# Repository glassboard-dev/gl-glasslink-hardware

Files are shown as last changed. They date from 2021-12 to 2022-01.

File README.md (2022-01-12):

<p align="center">
  <h3 align="center">⚡ Glasslink</h3>
  <p align="center">
    CMSIS-DAP Compatible Debugger & Programmer for ARM M-Cores
  </p>
</p>

<br />


### Development ⚡
The Glasslink hardware is currently developed in the open source ECAD software [KiCAD](https://www.kicad.org/). The board was created using as many of the included component symbols and footprints as possible. Any custom components are located in the ```Glasslink.lib``` and ```Glasslink.pretty``` files. Additional 3D models were also added to the designa and can be found in the ```models``` folder. The KiCAD [Teardrops](https://github.com/stimulu/kicad-teardrops) extension was used to add teardrops to SMD pads and Vias.

### Board Bring-up 🔼
Once you have a physical piece of hardware in hand, you can begin flashing and setting the device up for your use. The Glasslink hardware is intended to run the open-source firmware [DAPLink](https://github.com/ARMmbed/DAPLink/tree/develop) which supports Drag-N-Drop flashing of certain targets, CDC serial port, CMSIS-DAP WinUSB & HID debug channel as well as WebUSB debug channels. The tested Firwmare has been built using the current ```develop``` branch (as of ```12/10/2021```) using the ```GNU Arm Embedded Toolchain 10-2020-q4-major``` toolchain. More information on building standalone firmware or firmware intended for a specific target (utilizing MSC/Drag-N-Drop) - see [here](https://github.com/ARMmbed/DAPLink/tree/develop/docs).

Once you are ready to flash firmware to the DAPLink hardware, you can utilize the built-in NXP USB ROM Bootloader. A fresh piece of hardware should enumerate immediately into the bootloader when the USB is plugged in. Otherwise, you can hold down the ```nRESET``` pushbutton while plugging in the USB. The ROM Bootloader will enumerate as a MSD labeled ```CRP_DISABLED```.

#### Windows
On windows, to flash a piece of Glasslink hardware you can simply drag your compiled firmware onto the storage device found in File Explorer.

#### Linux
On linux, the ```dd``` command is used to write the firmware to your Glasslink hardware
```console
sudo dd if=lpc11u35_if.bin of=/media/user/CRP\ DISABLD/firmware.bin conv=notrunc
```

### Usage 💻
There are two common applications for utilizing the Glasslink debug probe: [PyOCD](https://pyocd.io/) and [OpenOCD](https://openocd.org/). Check the documentation for each on how to connect a probe, flash a target, debug, etc.

#### CDC Serial Port
The Glasslink hardware enumerates not only as a CMSIS-DAP probe, but also as a CDC serial port. This port can be utilized to send UART/serial data from your Target to a connected Host PC. On Windows a new ```COM``` port should enumerate and on Linux a new ```ACM``` port should enumerate when the Glasslink probe is connected.

To connect the Glasslink serial lines to your targets UART, please reference the 10pin ARM header pinout below. The current design assumes that you are creating your target hardware and have the ability to route your UART pins to the "unused" pins of the SWD header.

**```NOTE - The UART switching for TX<->RX and RX<->TX is done for you on the Glasslink hardware. The target TX pin sould go to pin 9 of the 10pin ARM header.```**

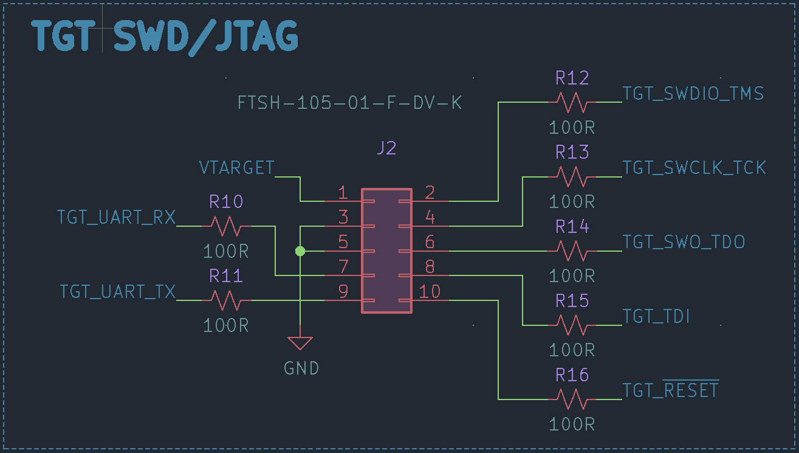
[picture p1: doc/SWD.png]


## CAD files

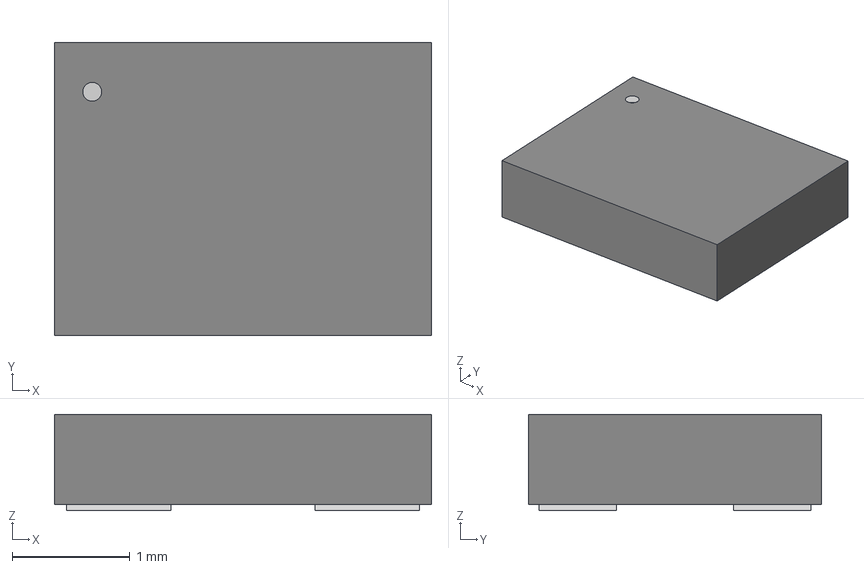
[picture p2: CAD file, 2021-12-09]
models/ECS-120-20-33-CKM-TR/2021-12-09_15-51-46/STEP/SMD_EXC-32_CRYSTAL_3P2X2P5_ECS.step
3.20 x 2.49 x 0.815 mm

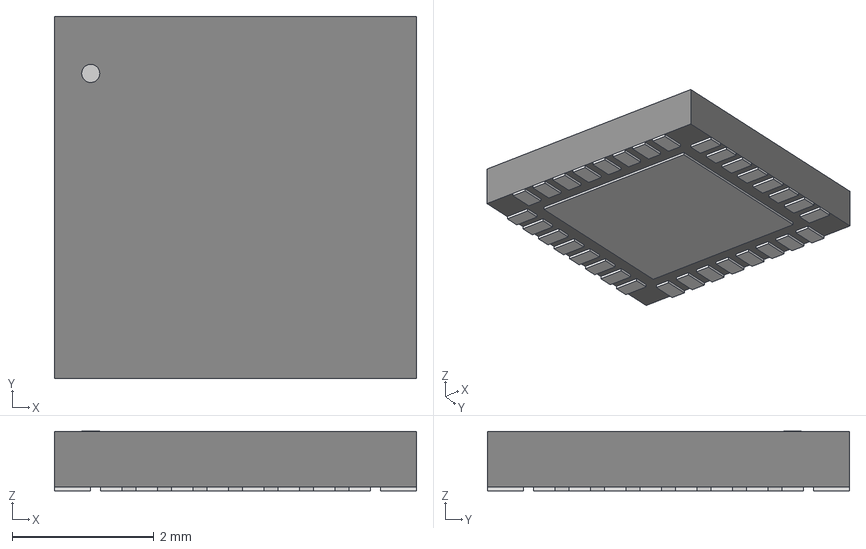
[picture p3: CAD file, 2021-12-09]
models/LPC11U35FHI33-501Y/2021-12-09_15-47-32/STEP/HVQFN32_SOT617-3_NXP.step
5.11 x 5.11 x 0.841 mm

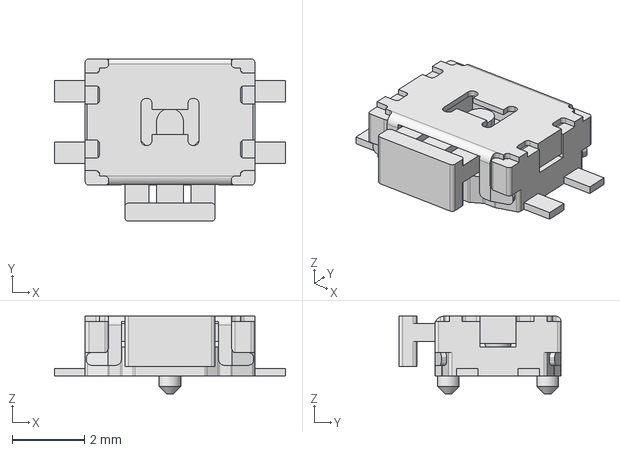
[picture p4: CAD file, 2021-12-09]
models/TL1014BF160QG/TL1014BFxxxQG.stp
6.40 x 4.50 x 2.15 mm

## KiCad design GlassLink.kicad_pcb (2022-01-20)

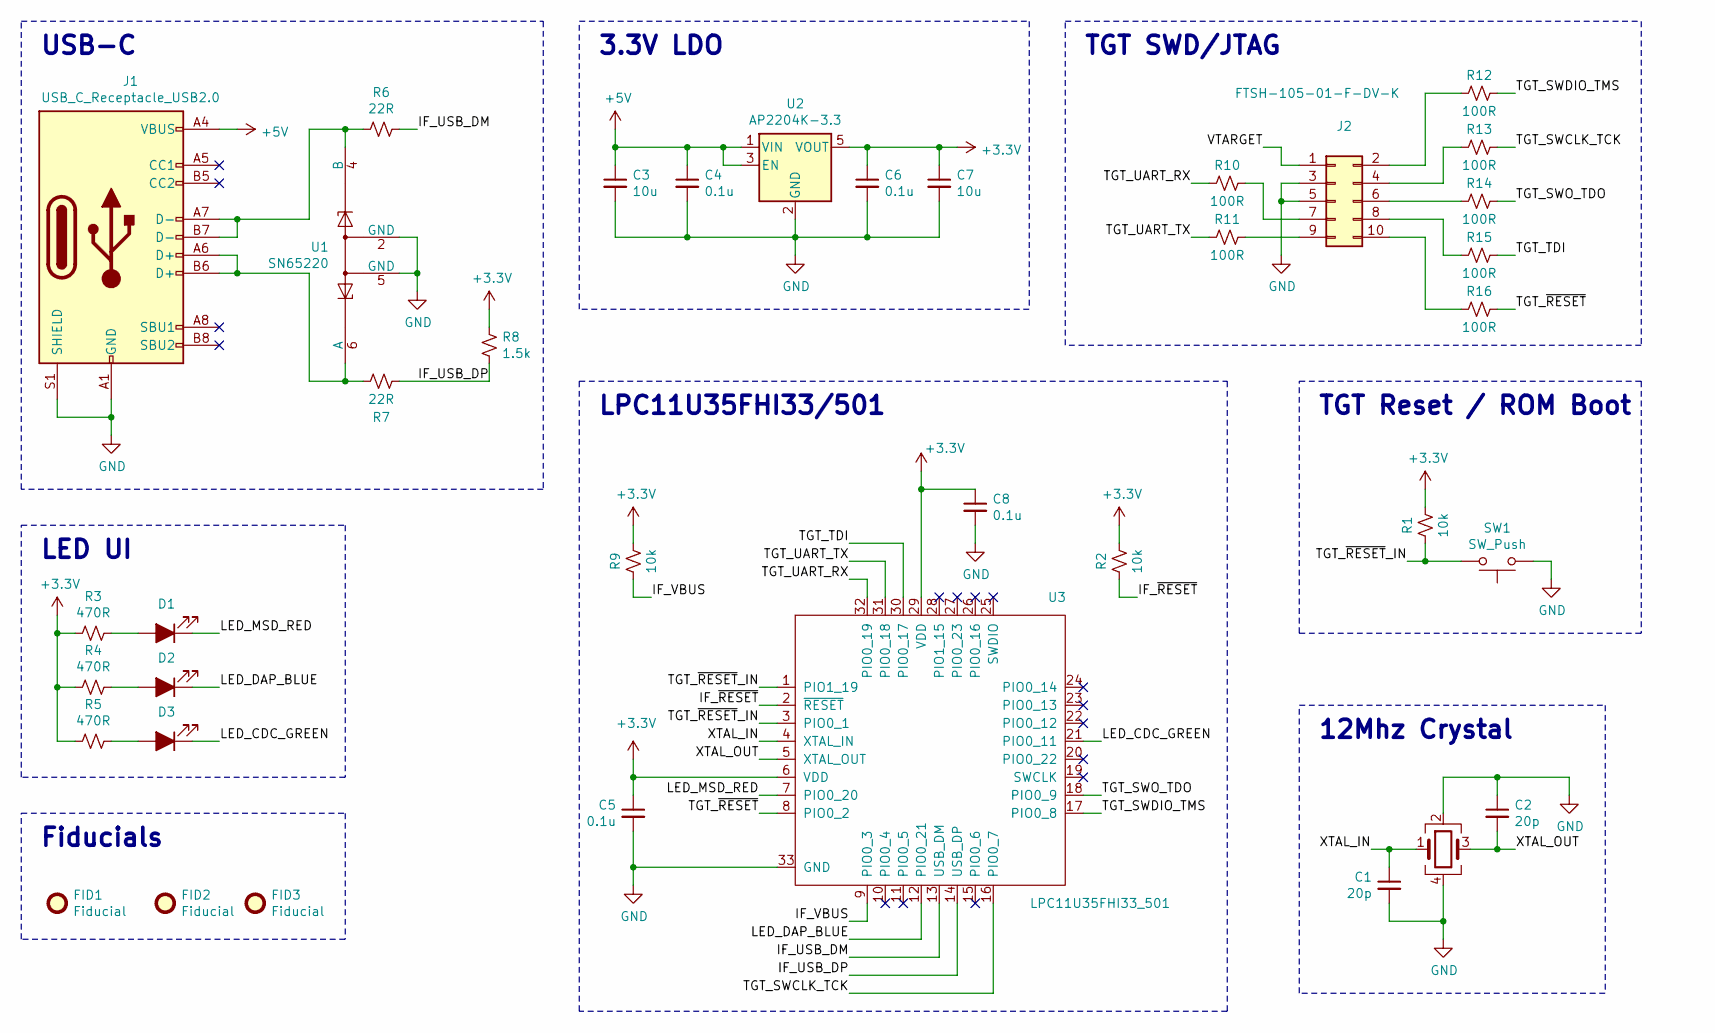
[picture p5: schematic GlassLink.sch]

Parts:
C1, C2: 20p; C_0402_1005Metric
C3, C7: 10u; C_0402_1005Metric
C4, C5, C6, C8: 0.1u; C_0402_1005Metric
D1: RED; LED_0603_1608Metric
D2: BLUE; LED_0603_1608Metric
D3: GREEN; LED_0603_1608Metric
FID1, FID2, FID3: Fiducial; Fiducial_0.5mm_Mask1mm
J1: USB_C_Receptacle_USB2.0; USB_C_Receptacle_GCT_USB4085
J2: FTSH-105-01-F-DV-K; PinHeader_2x05_P1.27mm_Vertical_SMD
R1, R2, R9: 10k; R_0402_1005Metric
R3, R4, R5: 470R; R_0402_1005Metric
R6, R7: 22R; R_0402_1005Metric
R8: 1.5k; R_0402_1005Metric
R10, R11, R12, R13, R14, R15, R16: 100R; R_0402_1005Metric
SW1: SW_Push; Panasonic_EVQPUL_EVQPUC
U1: SN65220; SOT-23-6
U2: AP2204K-3.3; SOT-23-5
U3: LPC11U35FHI33_501; QFN-32_EP_6.2x6.2_Pitch0.5mm
Y1: ECS-120-20-30B-TR; Crystal_SMD_5032-4Pin_5.0x3.2mm

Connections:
+3V3: C5.1, C6.1, C7.1, C8.1, R1.1, R2.1, R3.2, R4.2, R5.2, R8.1, R9.1, U2.5 (VOUT), U3.6 (VDD), U3.29 (VDD)
+5V: C3.1, C4.1, J1.A4 (VBUS), J1.A9 (VBUS), J1.B4 (VBUS), J1.B9 (VBUS), U2.1 (VIN), U2.3 (EN)
/IF_USB_DM: R6.1, U3.13 (USB_DM)
/IF_USB_DP: R7.2, R8.2, U3.14 (USB_DP)
/IF_VBUS: R9.2, U3.9 (PIO0_3)
/IF_~RESET: R2.2, U3.2 (~RESET)
/LED_CDC_GREEN: D3.1 (K), U3.21 (PIO0_11)
/LED_DAP_BLUE: D2.1 (K), U3.12 (PIO0_21)
/LED_MSD_RED: D1.1 (K), U3.7 (PIO0_20)
/TGT_SWCLK_TCK: R13.1, U3.16 (PIO0_7)
/TGT_SWDIO_TMS: R12.1, U3.17 (PIO0_8)
/TGT_SWO_TDO: R14.1, U3.18 (PIO0_9)
/TGT_TDI: R15.1, U3.30 (PIO0_17)
/TGT_UART_RX: R10.2, U3.32 (PIO0_19)
/TGT_UART_TX: R11.2, U3.31 (PIO0_18)
/TGT_~RESET: R16.1, U3.8 (PIO0_2)
/TGT_~RESET~_IN: R1.2, SW1.2, U3.1 (PIO1_19), U3.3 (PIO0_1)
/VTARGET: J2.1
/XTAL_IN: C1.1, U3.4 (XTAL_IN), Y1.1
/XTAL_OUT: C2.2, U3.5 (XTAL_OUT), Y1.3
GND: C1.2, C2.1, C3.2, C4.2, C5.2, C6.2, C7.2, C8.2, J1.A1 (GND), J1.A12 (GND), J1.B1 (GND), J1.B12 (GND), J1.S1 (SHIELD), J2.3, J2.5, SW1.1, U1.2 (GND), U1.5 (GND), U2.2 (GND), U3.33 (GND), Y1.2, Y1.4
unnamed: D1.2 (A), R3.1
unnamed: D2.2 (A), R4.1
unnamed: D3.2 (A), R5.1
unnamed: J1.A6 (D+), J1.B6 (D+), R7.1, U1.6 (A)
unnamed: J1.A7 (D-), J1.B7 (D-), R6.2, U1.4 (B)
unnamed: J2.2, R12.2
unnamed: J2.4, R13.2
unnamed: J2.6, R14.2
unnamed: J2.7, R10.1
unnamed: J2.8, R15.2
unnamed: J2.9, R11.1
unnamed: J2.10, R16.2

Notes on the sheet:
USB-C
3.3V LDO
TGT SWD/JTAG
LED UI
LPC11U35FHI33/501
12Mhz Crystal
TGT Reset / ROM Boot
Fiducials

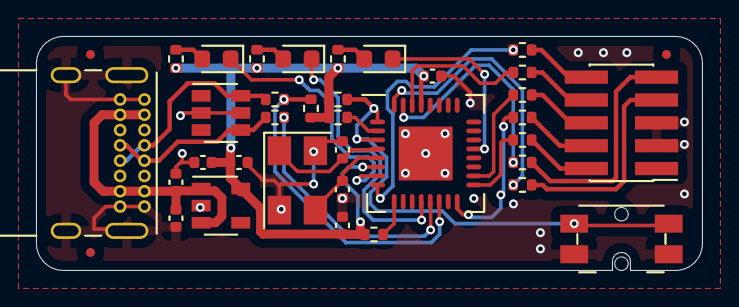
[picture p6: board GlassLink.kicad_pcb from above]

Board: 2 copper layers, 37.0 x 13.0 mm, 37 parts (0 on the bottom side), 32 nets.

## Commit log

2020-12-08 First commit of project files.
    [GlassLink-PCB.PcbDoc, GlassLink-PRJ.PrjPCB, [01] Title Page.SchDoc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]
2020-12-10 WIP: Components placed
    Awaiting track layout.
    [GlassLink-PCB.PcbDoc, GlassLink-PRJ.PrjPCB, [03] SCH-03.SchDoc]
2020-12-10 WIP: Layout finished
    In review
    [GlassLink-PCB.PcbDoc, GlassLink-PRJ.PrjPCB, [03] SCH-03.SchDoc]
2020-12-10 WIP: Added Type C Connector
    [[03] SCH-03.SchDoc]
2020-12-11 WIP: Clean DRC
    [[03] SCH-03.SchDoc]
2020-12-12 WIP: Updating Glassboard G Logo schematic symbol
    [[03] SCH-03.SchDoc]
2020-12-14 Submitting files ordered w/ PCBWay
    [GlassLink-PCB.DRL, GlassLink-PCB.GBL, GlassLink-PCB.GBO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]
2021-01-18 Updating for R0.2
    Updated test point position, added pull up on D+ line, and updated GlassLink net
    [GlassLink-PRJ.PrjPCB, [02] Schematic.SchDoc, [03] SCH-03.SchDoc]
2021-01-19 Clean DRC - Removing project outputs
    [GlassLink-PCB.DRL, GlassLink-PCB.GBL, GlassLink-PCB.GBO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]
2021-01-19 Order submitted to PCBWay for R0.2
2021-01-19 Removing unused schematic sheets
    [[02] Block Diagram.SchDoc, [04] SCH-04.SchDoc, [05] SCH-05.SchDoc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]
2021-01-27 Fixing missing G logo on bottom solder mask :(
    [GlassLink-PRJ.PrjPCB, [02] Schematic.SchDoc]
2021-02-25 Set CN1 to DNP and updated the outjob to support 3d-step exports
    [GlassLink-PRJ.PrjPCB, [02] Schematic.SchDoc]
2021-04-22 Changed micro for the LPC11U35
    [GlassLink-PRJ.PrjPCB, [02] Schematic.SchDoc]
2021-05-20 Replaced the 401 variant of the LPC11U35 for the 501 with 2k more SRAM
    [[02] Schematic.SchDoc]
2021-12-09 Adding KiCAD design files for the GlassLink R0.5
    [GlassLink-PRJ.PrjPCB, GlassLink.kicad_pcb, GlassLink.sch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]
2021-12-09 Pull TGT Reset to the TGT VCC instead of the prog VCC
    [GlassLink.kicad_pcb, GlassLink.sch]
2021-12-10 Adding Glassboard G logo
    [GlassLink.kicad_pcb]
2022-01-12 Pulling TGT_RESET to DAPLink 3.3V rail
    [GlassLink.kicad_pcb, GlassLink.sch]
2022-01-20 Fixing trace on top layer behind Glasslabs label
    [GlassLink.kicad_pcb]

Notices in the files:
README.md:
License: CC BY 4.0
